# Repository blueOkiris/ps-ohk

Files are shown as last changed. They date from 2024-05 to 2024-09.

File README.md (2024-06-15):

# Polymath-Studio One-Handed Keyboard

## Description

Type with only one hand

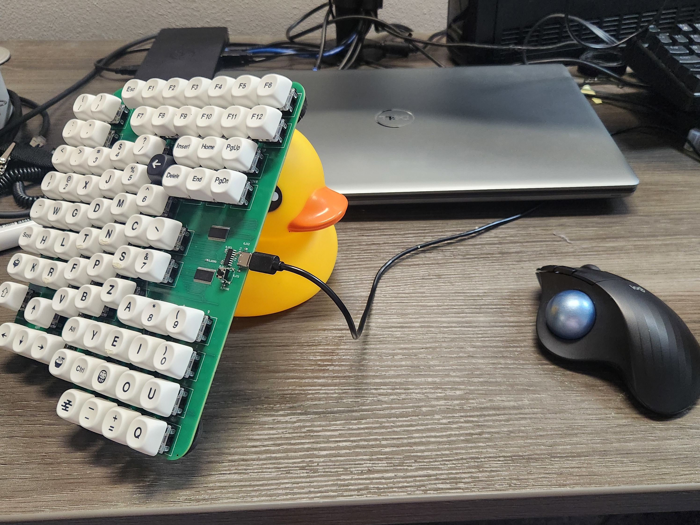
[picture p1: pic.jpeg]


Designed around

1) the most common letters used
2) relationships between sounds
3) the shape of a left hand
4) practicality

The PS-OHK (pronounced "psawk" [p͡sɑk̚]) aims to be the ultimate one-handed typing experience all without special modifiers (a standard key count) and a layout that is relatively easy to get used to.

## Build and Upload

Dependencies:

- arduino-cli
- make
- sdcc
- ch55xtool
- libusb

Build with `make -C fw`

Hold program button down, plug in, let go of program button, and run `make -C fw upload` within 3 seconds

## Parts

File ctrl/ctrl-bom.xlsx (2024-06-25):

Comment | Designator | Footprint | Part #
CH552G | IC_MCU1 | SOP-16 | C111292
10k Ohm | R_I2C2,R_I2C1,R_ADDR1,R_PROG1 | 0603
100nF | C2,C1 | 0603
5.1k Ohm | R_CC2,R_CC1 | 0603
PCA9505DGGY | IC_IOEXP2,IC_IOEXP1 | SOP50 P810X120-56N
USB-C Con | J_USB1 | USB-C 16P | C2894898

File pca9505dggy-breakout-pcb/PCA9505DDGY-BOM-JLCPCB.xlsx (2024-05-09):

Comment | Designator | Footprint | JLCPCB Part#(optional)
PCA9505DGG | IC1 | SOP-56P | C2669685

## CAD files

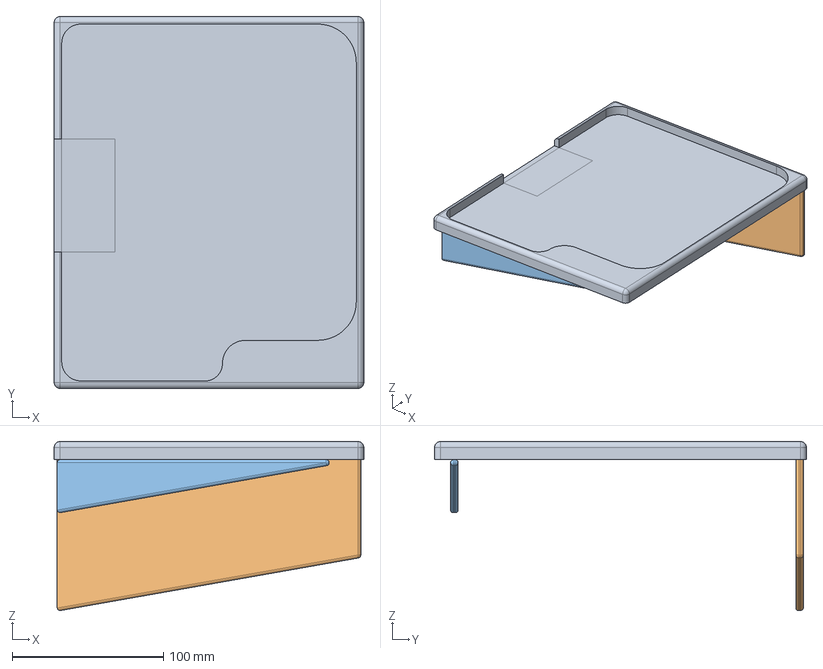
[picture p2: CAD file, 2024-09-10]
enclosure/ps-ohk-rh-enclosure.FCStd
204.5 x 245.6 x 111.6 mm
Keyboard Stand
Peg
Bottom Peg

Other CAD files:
enclosure/ps-ohk-rh-enclosure.stl

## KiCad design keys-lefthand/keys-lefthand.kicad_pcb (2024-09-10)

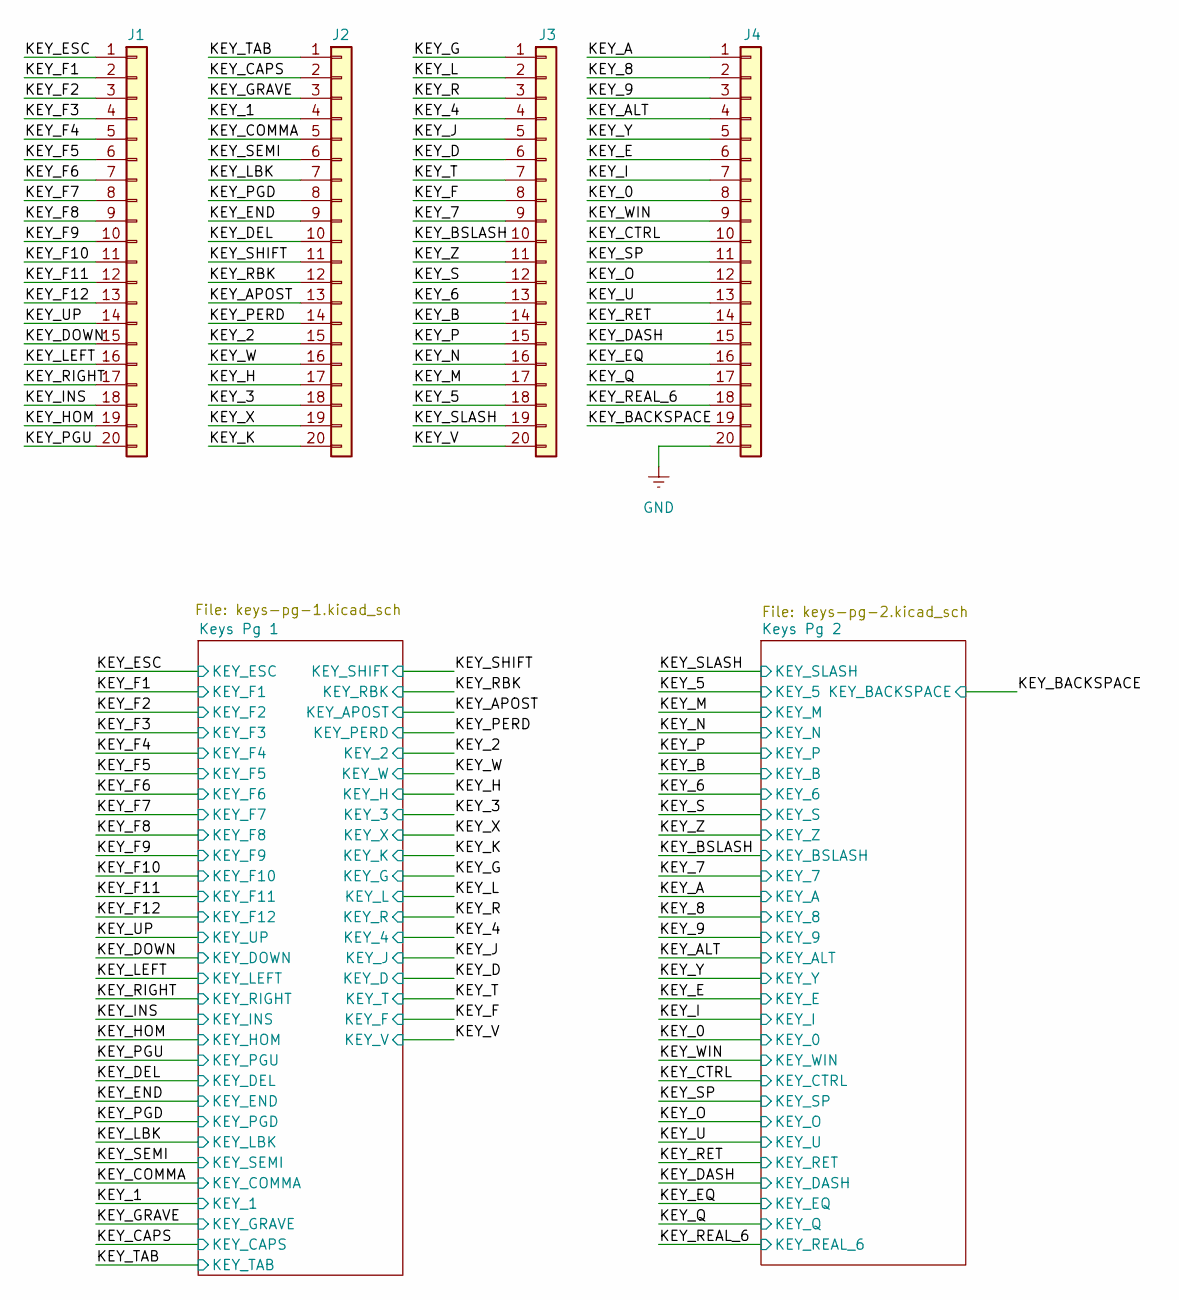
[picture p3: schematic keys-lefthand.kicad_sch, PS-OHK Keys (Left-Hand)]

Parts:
J1, J2, J3, J4: Conn_01x20; PinHeader_1x20_P2.54mm_Vertical

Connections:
/KEY_0: J4.8; also elsewhere on the board
/KEY_1: J2.4; also elsewhere on the board
/KEY_2: J2.15; also elsewhere on the board
/KEY_3: J2.18; also elsewhere on the board
/KEY_4: J3.4; also elsewhere on the board
/KEY_5: J3.18; also elsewhere on the board
/KEY_6: J3.13; also elsewhere on the board
/KEY_7: J3.9; also elsewhere on the board
/KEY_8: J4.2; also elsewhere on the board
/KEY_9: J4.3; also elsewhere on the board
/KEY_A: J4.1; also elsewhere on the board
/KEY_ALT: J4.4; also elsewhere on the board
/KEY_APOST: J2.13; also elsewhere on the board
/KEY_B: J3.14; also elsewhere on the board
/KEY_BACKSPACE: J4.19; also elsewhere on the board
/KEY_BSLASH: J3.10; also elsewhere on the board
/KEY_CAPS: J2.2; also elsewhere on the board
/KEY_COMMA: J2.5; also elsewhere on the board
/KEY_CTRL: J4.10; also elsewhere on the board
/KEY_D: J3.6; also elsewhere on the board
/KEY_DASH: J4.15; also elsewhere on the board
/KEY_DEL: J2.10; also elsewhere on the board
/KEY_DOWN: J1.15; also elsewhere on the board
/KEY_E: J4.6; also elsewhere on the board
/KEY_END: J2.9; also elsewhere on the board
/KEY_EQ: J4.16; also elsewhere on the board
/KEY_ESC: J1.1; also elsewhere on the board
/KEY_F: J3.8; also elsewhere on the board
/KEY_F1: J1.2; also elsewhere on the board
/KEY_F2: J1.3; also elsewhere on the board
/KEY_F3: J1.4; also elsewhere on the board
/KEY_F4: J1.5; also elsewhere on the board
/KEY_F5: J1.6; also elsewhere on the board
/KEY_F6: J1.7; also elsewhere on the board
/KEY_F7: J1.8; also elsewhere on the board
/KEY_F8: J1.9; also elsewhere on the board
/KEY_F9: J1.10; also elsewhere on the board
/KEY_F10: J1.11; also elsewhere on the board
/KEY_F11: J1.12; also elsewhere on the board
/KEY_F12: J1.13; also elsewhere on the board
/KEY_G: J3.1; also elsewhere on the board
/KEY_GRAVE: J2.3; also elsewhere on the board
/KEY_H: J2.17; also elsewhere on the board
/KEY_HOM: J1.19; also elsewhere on the board
/KEY_I: J4.7; also elsewhere on the board
/KEY_INS: J1.18; also elsewhere on the board
/KEY_J: J3.5; also elsewhere on the board
/KEY_K: J2.20; also elsewhere on the board
/KEY_L: J3.2; also elsewhere on the board
/KEY_LBK: J2.7; also elsewhere on the board
/KEY_LEFT: J1.16; also elsewhere on the board
/KEY_M: J3.17; also elsewhere on the board
/KEY_N: J3.16; also elsewhere on the board
/KEY_O: J4.12; also elsewhere on the board
/KEY_P: J3.15; also elsewhere on the board
/KEY_PERD: J2.14; also elsewhere on the board
/KEY_PGD: J2.8; also elsewhere on the board
/KEY_PGU: J1.20; also elsewhere on the board
/KEY_Q: J4.17; also elsewhere on the board
/KEY_R: J3.3; also elsewhere on the board
/KEY_RBK: J2.12; also elsewhere on the board
/KEY_REAL_6: J4.18; also elsewhere on the board
/KEY_RET: J4.14; also elsewhere on the board
/KEY_RIGHT: J1.17; also elsewhere on the board
/KEY_S: J3.12; also elsewhere on the board
/KEY_SEMI: J2.6; also elsewhere on the board
/KEY_SHIFT: J2.11; also elsewhere on the board
/KEY_SLASH: J3.19; also elsewhere on the board
/KEY_SP: J4.11; also elsewhere on the board
/KEY_T: J3.7; also elsewhere on the board
/KEY_TAB: J2.1; also elsewhere on the board
/KEY_U: J4.13; also elsewhere on the board
/KEY_UP: J1.14; also elsewhere on the board
/KEY_V: J3.20; also elsewhere on the board
/KEY_W: J2.16; also elsewhere on the board
/KEY_WIN: J4.9; also elsewhere on the board
/KEY_X: J2.19; also elsewhere on the board
/KEY_Y: J4.5; also elsewhere on the board
/KEY_Z: J3.11; also elsewhere on the board
GND: J4.20; also elsewhere on the board

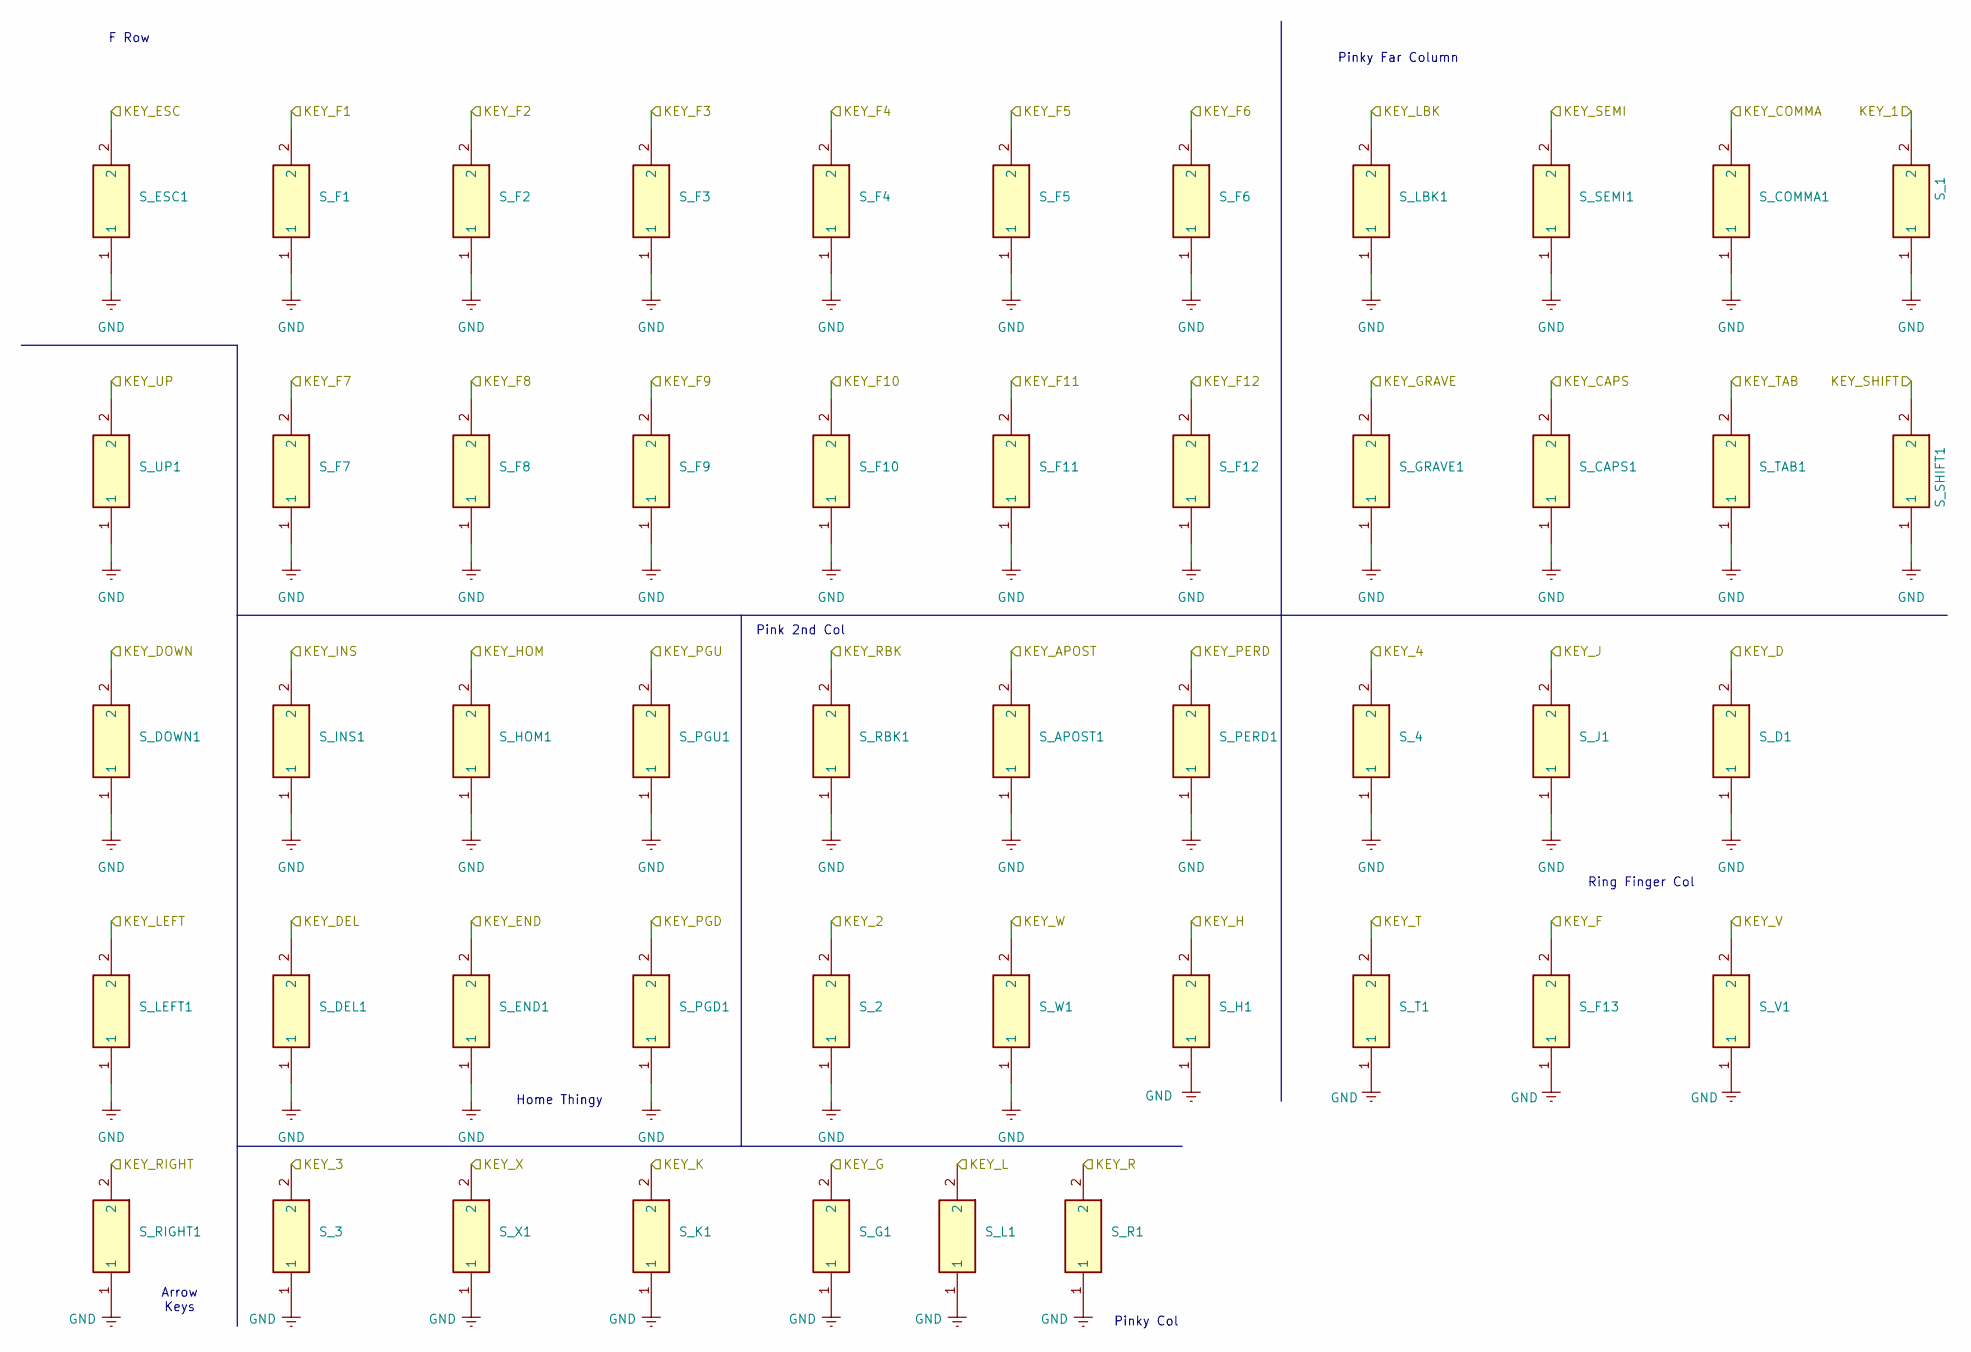
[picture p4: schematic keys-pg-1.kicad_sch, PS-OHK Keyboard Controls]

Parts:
S_1, S_2, S_3, S_4: COM13834; Mouser Part Number 474-COM-13834
S_APOST1: COM13834; Mouser Part Number 474-COM-13834
S_CAPS1: COM13834; Mouser Part Number 474-COM-13834
S_COMMA1: COM13834; Mouser Part Number 474-COM-13834
S_D1: COM13834; Mouser Part Number 474-COM-13834
S_DEL1: COM13834; Mouser Part Number 474-COM-13834
S_DOWN1: COM13834; Mouser Part Number 474-COM-13834
S_END1: COM13834; Mouser Part Number 474-COM-13834
S_ESC1: COM13834; Mouser Part Number 474-COM-13834
S_F1, S_F2, S_F3, S_F4, S_F5, S_F6, S_F7, S_F8, S_F9, S_F10, S_F11, S_F12, S_F13: COM13834; Mouser Part Number 474-COM-13834
S_G1: COM13834; Mouser Part Number 474-COM-13834
S_GRAVE1: COM13834; Mouser Part Number 474-COM-13834
S_H1: COM13834; Mouser Part Number 474-COM-13834
S_HOM1: COM13834; Mouser Part Number 474-COM-13834
S_INS1: COM13834; Mouser Part Number 474-COM-13834
S_J1: COM13834; Mouser Part Number 474-COM-13834
S_K1: COM13834; Mouser Part Number 474-COM-13834
S_L1: COM13834; Mouser Part Number 474-COM-13834
S_LBK1: COM13834; Mouser Part Number 474-COM-13834
S_LEFT1: COM13834; Mouser Part Number 474-COM-13834
S_PERD1: COM13834; Mouser Part Number 474-COM-13834
S_PGD1: COM13834; Mouser Part Number 474-COM-13834
S_PGU1: COM13834; Mouser Part Number 474-COM-13834
S_R1: COM13834; Mouser Part Number 474-COM-13834
S_RBK1: COM13834; Mouser Part Number 474-COM-13834
S_RIGHT1: COM13834; Mouser Part Number 474-COM-13834
S_SEMI1: COM13834; Mouser Part Number 474-COM-13834
S_SHIFT1: COM13834; Mouser Part Number 474-COM-13834
S_T1: COM13834; Mouser Part Number 474-COM-13834
S_TAB1: COM13834; Mouser Part Number 474-COM-13834
S_UP1: COM13834; Mouser Part Number 474-COM-13834
S_V1: COM13834; Mouser Part Number 474-COM-13834
S_W1: COM13834; Mouser Part Number 474-COM-13834
S_X1: COM13834; Mouser Part Number 474-COM-13834

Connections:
/KEY_1: S_1.2; also elsewhere on the board
/KEY_2: S_2.2; also elsewhere on the board
/KEY_3: S_3.2; also elsewhere on the board
/KEY_4: S_4.2; also elsewhere on the board
/KEY_APOST: S_APOST1.2; also elsewhere on the board
/KEY_CAPS: S_CAPS1.2; also elsewhere on the board
/KEY_COMMA: S_COMMA1.2; also elsewhere on the board
/KEY_D: S_D1.2; also elsewhere on the board
/KEY_DEL: S_DEL1.2; also elsewhere on the board
/KEY_DOWN: S_DOWN1.2; also elsewhere on the board
/KEY_END: S_END1.2; also elsewhere on the board
/KEY_ESC: S_ESC1.2; also elsewhere on the board
/KEY_F: S_F13.2; also elsewhere on the board
/KEY_F1: S_F1.2; also elsewhere on the board
/KEY_F2: S_F2.2; also elsewhere on the board
/KEY_F3: S_F3.2; also elsewhere on the board
/KEY_F4: S_F4.2; also elsewhere on the board
/KEY_F5: S_F5.2; also elsewhere on the board
/KEY_F6: S_F6.2; also elsewhere on the board
/KEY_F7: S_F7.2; also elsewhere on the board
/KEY_F8: S_F8.2; also elsewhere on the board
/KEY_F9: S_F9.2; also elsewhere on the board
/KEY_F10: S_F10.2; also elsewhere on the board
/KEY_F11: S_F11.2; also elsewhere on the board
/KEY_F12: S_F12.2; also elsewhere on the board
/KEY_G: S_G1.2; also elsewhere on the board
/KEY_GRAVE: S_GRAVE1.2; also elsewhere on the board
/KEY_H: S_H1.2; also elsewhere on the board
/KEY_HOM: S_HOM1.2; also elsewhere on the board
/KEY_INS: S_INS1.2; also elsewhere on the board
/KEY_J: S_J1.2; also elsewhere on the board
/KEY_K: S_K1.2; also elsewhere on the board
/KEY_L: S_L1.2; also elsewhere on the board
/KEY_LBK: S_LBK1.2; also elsewhere on the board
/KEY_LEFT: S_LEFT1.2; also elsewhere on the board
/KEY_PERD: S_PERD1.2; also elsewhere on the board
/KEY_PGD: S_PGD1.2; also elsewhere on the board
/KEY_PGU: S_PGU1.2; also elsewhere on the board
/KEY_R: S_R1.2; also elsewhere on the board
/KEY_RBK: S_RBK1.2; also elsewhere on the board
/KEY_RIGHT: S_RIGHT1.2; also elsewhere on the board
/KEY_SEMI: S_SEMI1.2; also elsewhere on the board
/KEY_SHIFT: S_SHIFT1.2; also elsewhere on the board
/KEY_T: S_T1.2; also elsewhere on the board
/KEY_TAB: S_TAB1.2; also elsewhere on the board
/KEY_UP: S_UP1.2; also elsewhere on the board
/KEY_V: S_V1.2; also elsewhere on the board
/KEY_W: S_W1.2; also elsewhere on the board
/KEY_X: S_X1.2; also elsewhere on the board
GND: S_1.1, S_2.1, S_3.1, S_4.1, S_APOST1.1, S_CAPS1.1, S_COMMA1.1, S_D1.1, S_DEL1.1, S_DOWN1.1, S_END1.1, S_ESC1.1, S_F1.1, S_F2.1, S_F3.1, S_F4.1, S_F5.1, S_F6.1, S_F7.1, S_F8.1, S_F9.1, S_F10.1, S_F11.1, S_F12.1, S_F13.1, S_G1.1, S_GRAVE1.1, S_H1.1, S_HOM1.1, S_INS1.1, S_J1.1, S_K1.1, S_L1.1, S_LBK1.1, S_LEFT1.1, S_PERD1.1, S_PGD1.1, S_PGU1.1, S_R1.1, S_RBK1.1, S_RIGHT1.1, S_SEMI1.1, S_SHIFT1.1, S_T1.1, S_TAB1.1, S_UP1.1, S_V1.1, S_W1.1, S_X1.1; also elsewhere on the board

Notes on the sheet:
Pink 2nd Col
Pinky Far Column
Pinky Col
Ring Finger Col
Arrow Keys
Home Thingy
F Row

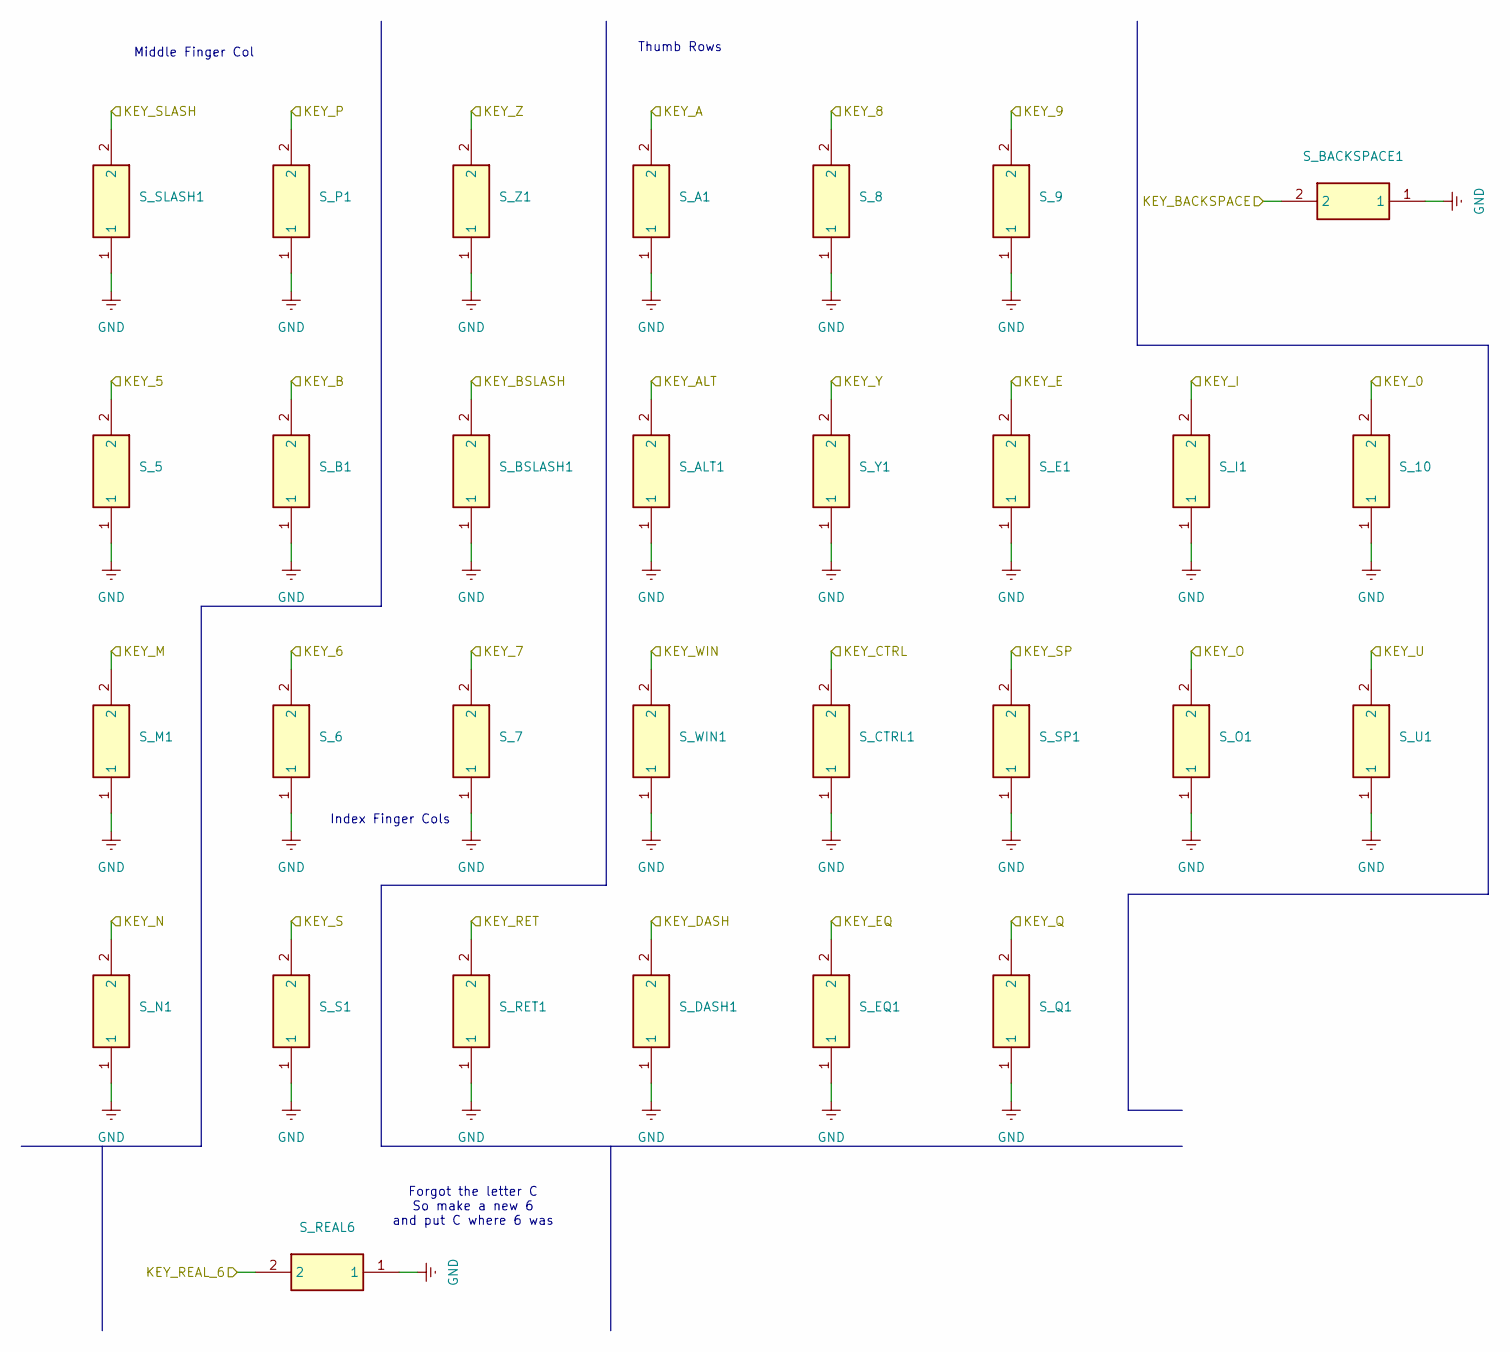
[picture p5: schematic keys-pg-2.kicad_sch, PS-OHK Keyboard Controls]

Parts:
S_5, S_6, S_7, S_8, S_9, S_10: COM13834; Mouser Part Number 474-COM-13834
S_A1: COM13834; Mouser Part Number 474-COM-13834
S_ALT1: COM13834; Mouser Part Number 474-COM-13834
S_B1: COM13834; Mouser Part Number 474-COM-13834
S_BACKSPACE1: COM13834; Mouser Part Number 474-COM-13834
S_BSLASH1: COM13834; Mouser Part Number 474-COM-13834
S_CTRL1: COM13834; Mouser Part Number 474-COM-13834
S_DASH1: COM13834; Mouser Part Number 474-COM-13834
S_E1: COM13834; Mouser Part Number 474-COM-13834
S_EQ1: COM13834; Mouser Part Number 474-COM-13834
S_I1: COM13834; Mouser Part Number 474-COM-13834
S_M1: COM13834; Mouser Part Number 474-COM-13834
S_N1: COM13834; Mouser Part Number 474-COM-13834
S_O1: COM13834; Mouser Part Number 474-COM-13834
S_P1: COM13834; Mouser Part Number 474-COM-13834
S_Q1: COM13834; Mouser Part Number 474-COM-13834
S_REAL6: COM13834; Mouser Part Number 474-COM-13834
S_RET1: COM13834; Mouser Part Number 474-COM-13834
S_S1: COM13834; Mouser Part Number 474-COM-13834
S_SLASH1: COM13834; Mouser Part Number 474-COM-13834
S_SP1: COM13834; Mouser Part Number 474-COM-13834
S_U1: COM13834; Mouser Part Number 474-COM-13834
S_WIN1: COM13834; Mouser Part Number 474-COM-13834
S_Y1: COM13834; Mouser Part Number 474-COM-13834
S_Z1: COM13834; Mouser Part Number 474-COM-13834

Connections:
/KEY_0: S_10.2; also elsewhere on the board
/KEY_5: S_5.2; also elsewhere on the board
/KEY_6: S_6.2; also elsewhere on the board
/KEY_7: S_7.2; also elsewhere on the board
/KEY_8: S_8.2; also elsewhere on the board
/KEY_9: S_9.2; also elsewhere on the board
/KEY_A: S_A1.2; also elsewhere on the board
/KEY_ALT: S_ALT1.2; also elsewhere on the board
/KEY_B: S_B1.2; also elsewhere on the board
/KEY_BACKSPACE: S_BACKSPACE1.2; also elsewhere on the board
/KEY_BSLASH: S_BSLASH1.2; also elsewhere on the board
/KEY_CTRL: S_CTRL1.2; also elsewhere on the board
/KEY_DASH: S_DASH1.2; also elsewhere on the board
/KEY_E: S_E1.2; also elsewhere on the board
/KEY_EQ: S_EQ1.2; also elsewhere on the board
/KEY_I: S_I1.2; also elsewhere on the board
/KEY_M: S_M1.2; also elsewhere on the board
/KEY_N: S_N1.2; also elsewhere on the board
/KEY_O: S_O1.2; also elsewhere on the board
/KEY_P: S_P1.2; also elsewhere on the board
/KEY_Q: S_Q1.2; also elsewhere on the board
/KEY_REAL_6: S_REAL6.2; also elsewhere on the board
/KEY_RET: S_RET1.2; also elsewhere on the board
/KEY_S: S_S1.2; also elsewhere on the board
/KEY_SLASH: S_SLASH1.2; also elsewhere on the board
/KEY_SP: S_SP1.2; also elsewhere on the board
/KEY_U: S_U1.2; also elsewhere on the board
/KEY_WIN: S_WIN1.2; also elsewhere on the board
/KEY_Y: S_Y1.2; also elsewhere on the board
/KEY_Z: S_Z1.2; also elsewhere on the board
GND: S_5.1, S_6.1, S_7.1, S_8.1, S_9.1, S_10.1, S_A1.1, S_ALT1.1, S_B1.1, S_BACKSPACE1.1, S_BSLASH1.1, S_CTRL1.1, S_DASH1.1, S_E1.1, S_EQ1.1, S_I1.1, S_M1.1, S_N1.1, S_O1.1, S_P1.1, S_Q1.1, S_REAL6.1, S_RET1.1, S_S1.1, S_SLASH1.1, S_SP1.1, S_U1.1, S_WIN1.1, S_Y1.1, S_Z1.1; also elsewhere on the board

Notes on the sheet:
Index Finger Cols
Forgot the letter C So make a new 6 and put C where 6 was
Thumb Rows
Middle Finger Col

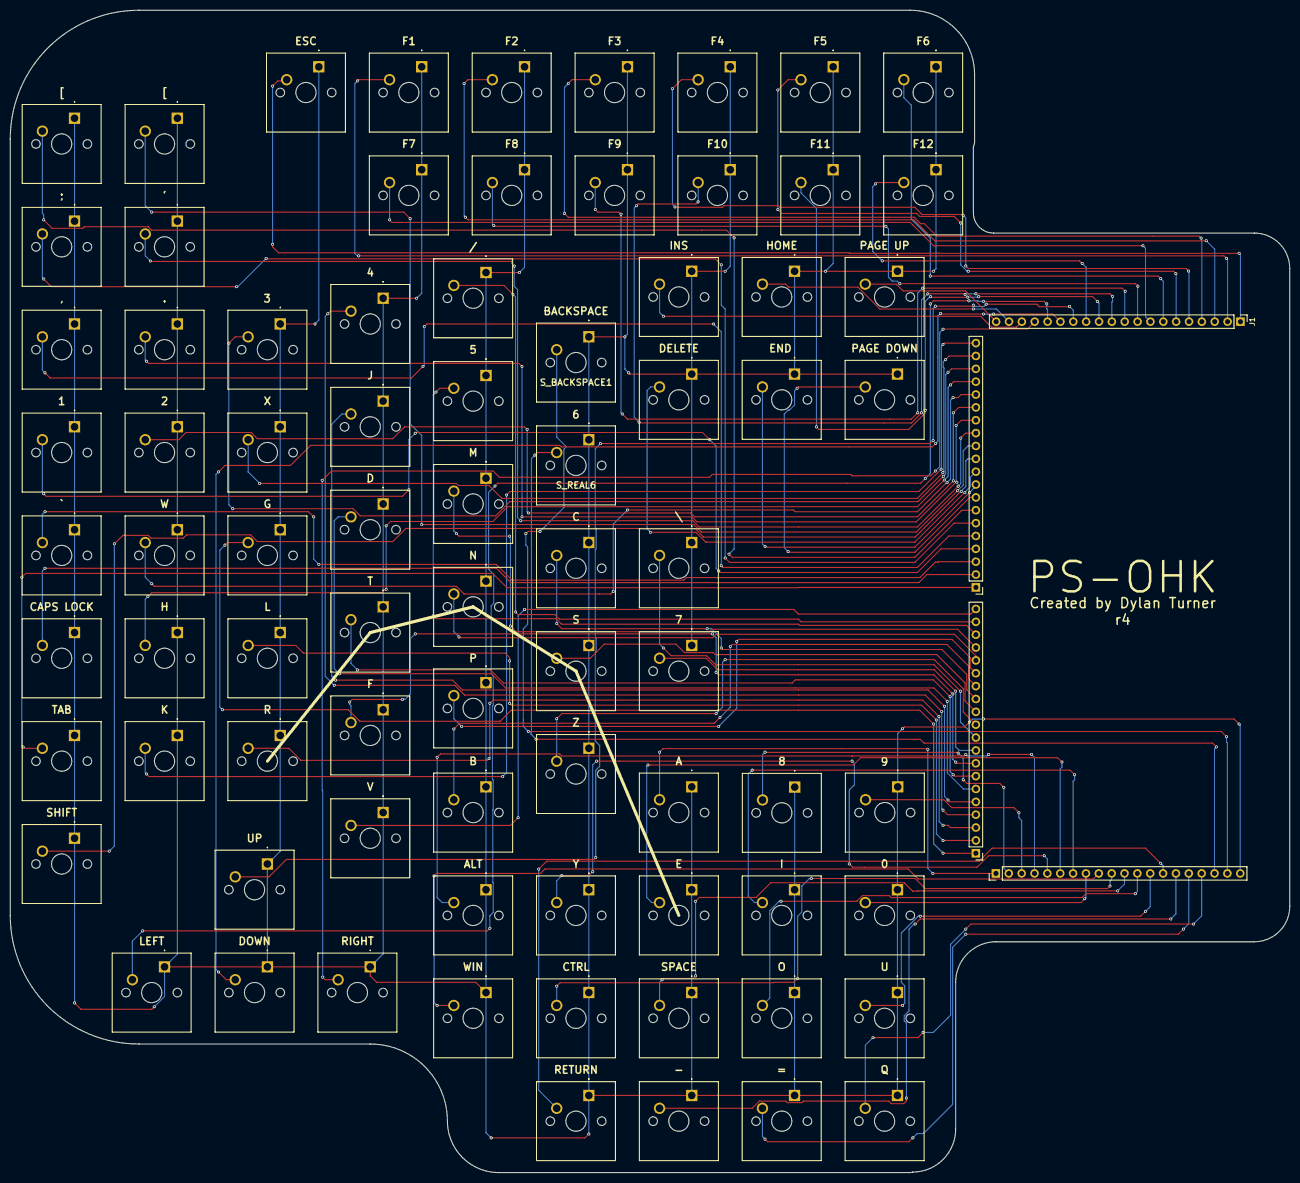
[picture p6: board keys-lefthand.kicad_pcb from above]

Board: 2 copper layers, 252.8 x 229.6 mm, 83 parts (0 on the bottom side), 80 nets.

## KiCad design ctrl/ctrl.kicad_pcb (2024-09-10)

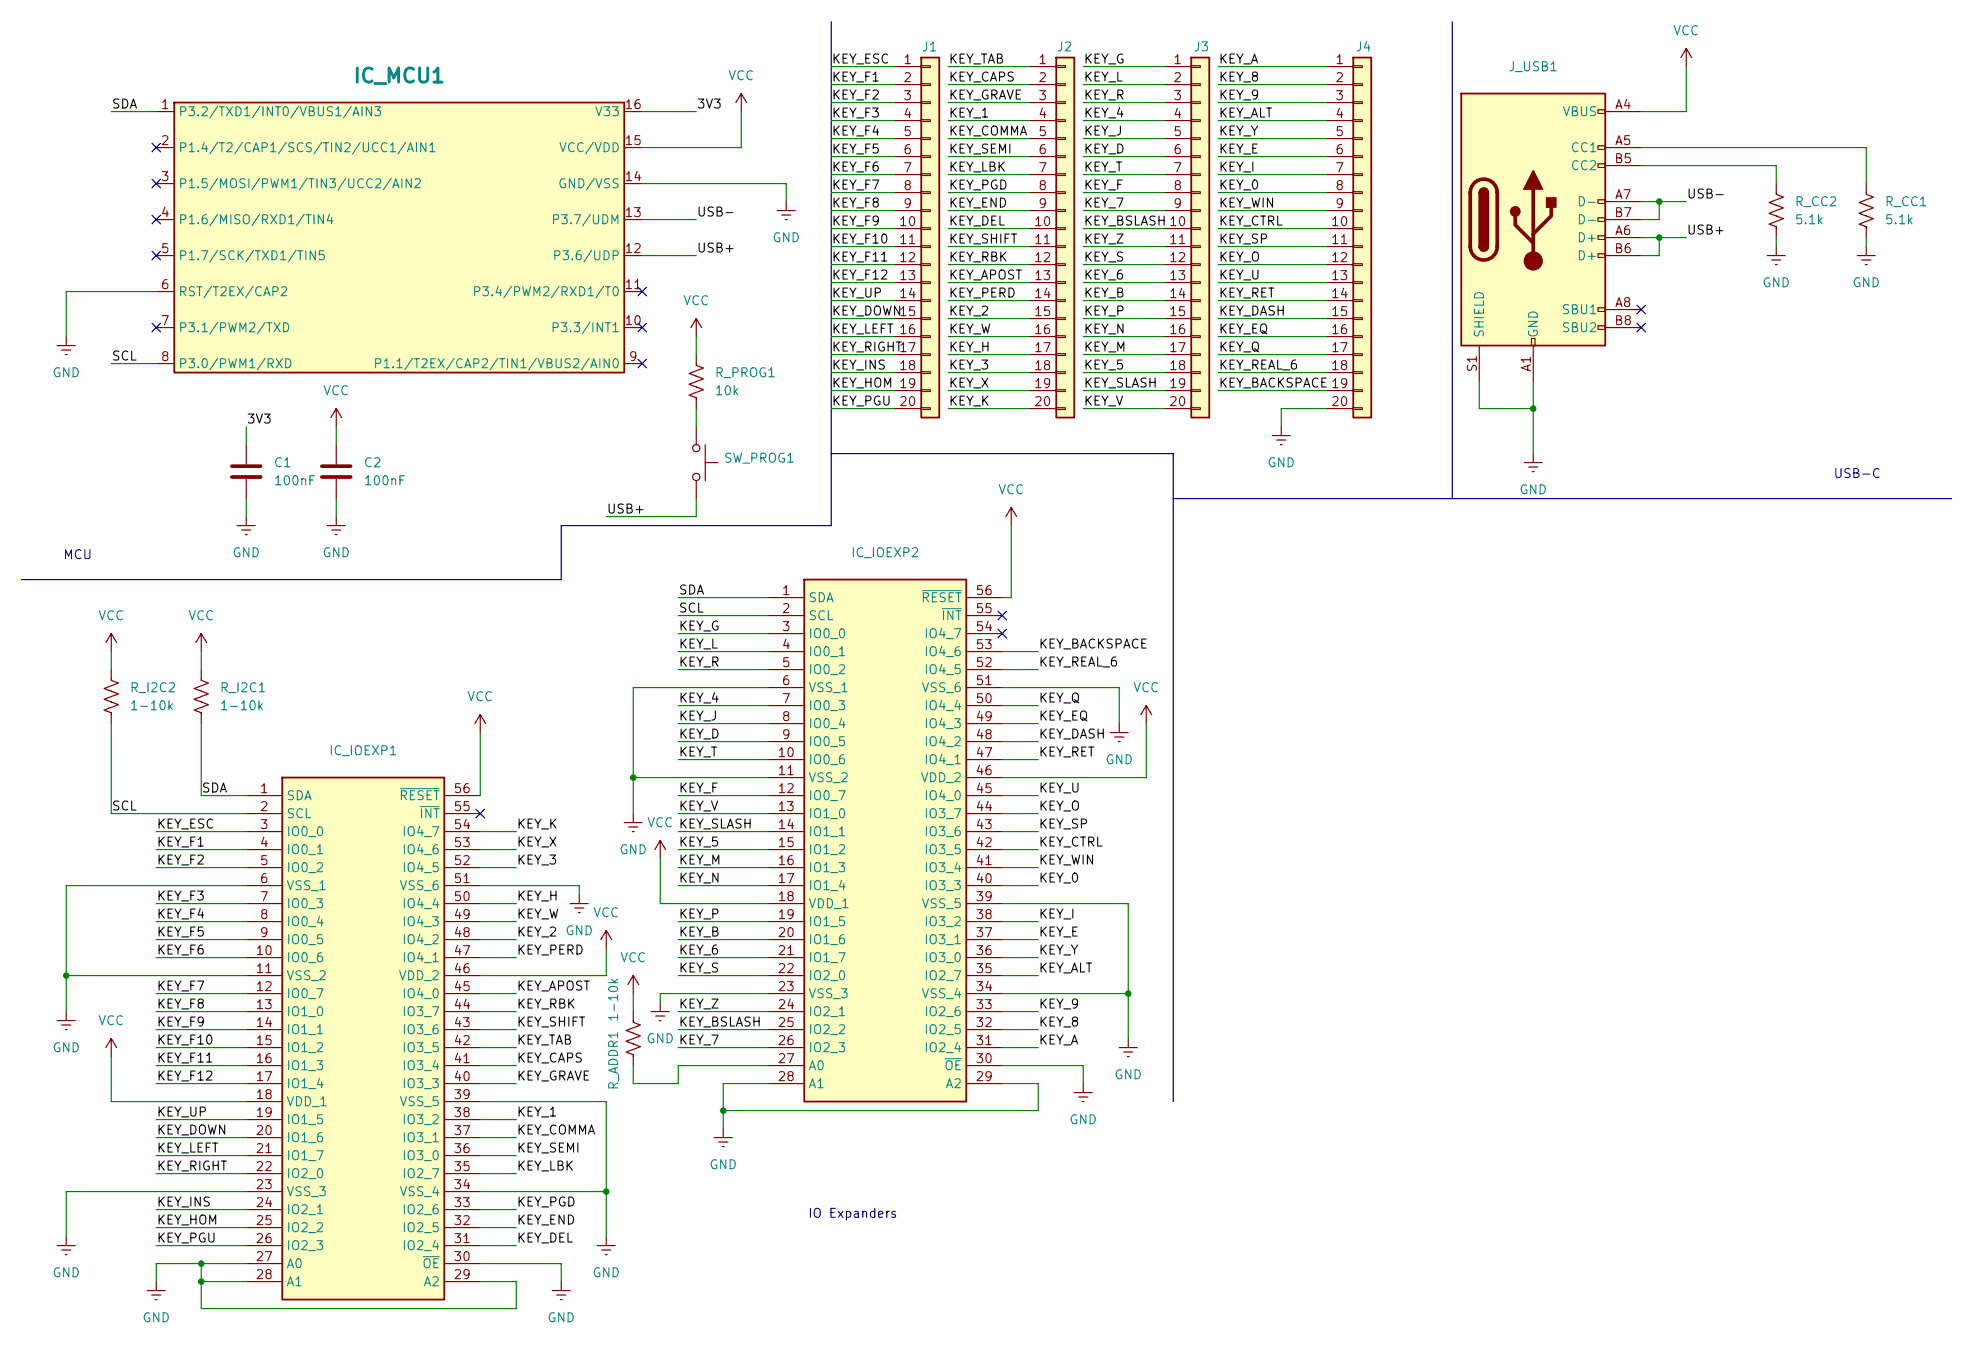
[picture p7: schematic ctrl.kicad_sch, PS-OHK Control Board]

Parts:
C1, C2: 100nF; C_0603_1608Metric
IC_IOEXP1, IC_IOEXP2: SOP50P810X120-56N; Mouser Part Number 771-PCA9505DGGY
IC_MCU1: SOIC-16_3.9x9.9mm_Pitch1.27mm
J1, J2, J3, J4: Conn_01x20; PinHeader_1x20_P2.54mm_Vertical
J_USB1: USB_C_Receptacle_HCTL_HC-TYPE-C-16P-01A
R_ADDR1: 1-10k; R_0603_1608Metric
R_CC1, R_CC2: 5.1k; R_0603_1608Metric
R_I2C1, R_I2C2: 1-10k; R_0603_1608Metric
R_PROG1: 10k; R_0603_1608Metric
SW_PROG1: SW_Push_1P1T_NO_6x6mm_H9.5mm

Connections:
/3V3: C1.1, IC_MCU1.16 (V33)
/KEY_0: IC_IOEXP2.40 (IO3_3), J4.8
/KEY_1: IC_IOEXP1.38 (IO3_2), J2.4
/KEY_2: IC_IOEXP1.48 (IO4_2), J2.15
/KEY_3: IC_IOEXP1.52 (IO4_5), J2.18
/KEY_4: IC_IOEXP2.7 (IO0_3), J3.4
/KEY_5: IC_IOEXP2.15 (IO1_2), J3.18
/KEY_6: IC_IOEXP2.21 (IO1_7), J3.13
/KEY_7: IC_IOEXP2.26 (IO2_3), J3.9
/KEY_8: IC_IOEXP2.32 (IO2_5), J4.2
/KEY_9: IC_IOEXP2.33 (IO2_6), J4.3
/KEY_A: IC_IOEXP2.31 (IO2_4), J4.1
/KEY_ALT: IC_IOEXP2.35 (IO2_7), J4.4
/KEY_APOST: IC_IOEXP1.45 (IO4_0), J2.13
/KEY_B: IC_IOEXP2.20 (IO1_6), J3.14
/KEY_BACKSPACE: IC_IOEXP2.53 (IO4_6), J4.19
/KEY_BSLASH: IC_IOEXP2.25 (IO2_2), J3.10
/KEY_CAPS: IC_IOEXP1.41 (IO3_4), J2.2
/KEY_COMMA: IC_IOEXP1.37 (IO3_1), J2.5
/KEY_CTRL: IC_IOEXP2.42 (IO3_5), J4.10
/KEY_D: IC_IOEXP2.9 (IO0_5), J3.6
/KEY_DASH: IC_IOEXP2.48 (IO4_2), J4.15
/KEY_DEL: IC_IOEXP1.31 (IO2_4), J2.10
/KEY_DOWN: IC_IOEXP1.20 (IO1_6), J1.15
/KEY_E: IC_IOEXP2.37 (IO3_1), J4.6
/KEY_END: IC_IOEXP1.32 (IO2_5), J2.9
/KEY_EQ: IC_IOEXP2.49 (IO4_3), J4.16
/KEY_ESC: IC_IOEXP1.3 (IO0_0), J1.1
/KEY_F: IC_IOEXP2.12 (IO0_7), J3.8
/KEY_F1: IC_IOEXP1.4 (IO0_1), J1.2
/KEY_F2: IC_IOEXP1.5 (IO0_2), J1.3
/KEY_F3: IC_IOEXP1.7 (IO0_3), J1.4
/KEY_F4: IC_IOEXP1.8 (IO0_4), J1.5
/KEY_F5: IC_IOEXP1.9 (IO0_5), J1.6
/KEY_F6: IC_IOEXP1.10 (IO0_6), J1.7
/KEY_F7: IC_IOEXP1.12 (IO0_7), J1.8
/KEY_F8: IC_IOEXP1.13 (IO1_0), J1.9
/KEY_F9: IC_IOEXP1.14 (IO1_1), J1.10
/KEY_F10: IC_IOEXP1.15 (IO1_2), J1.11
/KEY_F11: IC_IOEXP1.16 (IO1_3), J1.12
/KEY_F12: IC_IOEXP1.17 (IO1_4), J1.13
/KEY_G: IC_IOEXP2.3 (IO0_0), J3.1
/KEY_GRAVE: IC_IOEXP1.40 (IO3_3), J2.3
/KEY_H: IC_IOEXP1.50 (IO4_4), J2.17
/KEY_HOM: IC_IOEXP1.25 (IO2_2), J1.19
/KEY_I: IC_IOEXP2.38 (IO3_2), J4.7
/KEY_INS: IC_IOEXP1.24 (IO2_1), J1.18
/KEY_J: IC_IOEXP2.8 (IO0_4), J3.5
/KEY_K: IC_IOEXP1.54 (IO4_7), J2.20
/KEY_L: IC_IOEXP2.4 (IO0_1), J3.2
/KEY_LBK: IC_IOEXP1.35 (IO2_7), J2.7
/KEY_LEFT: IC_IOEXP1.21 (IO1_7), J1.16
/KEY_M: IC_IOEXP2.16 (IO1_3), J3.17
/KEY_N: IC_IOEXP2.17 (IO1_4), J3.16
/KEY_O: IC_IOEXP2.44 (IO3_7), J4.12
/KEY_P: IC_IOEXP2.19 (IO1_5), J3.15
/KEY_PERD: IC_IOEXP1.47 (IO4_1), J2.14
/KEY_PGD: IC_IOEXP1.33 (IO2_6), J2.8
/KEY_PGU: IC_IOEXP1.26 (IO2_3), J1.20
/KEY_Q: IC_IOEXP2.50 (IO4_4), J4.17
/KEY_R: IC_IOEXP2.5 (IO0_2), J3.3
/KEY_RBK: IC_IOEXP1.44 (IO3_7), J2.12
/KEY_REAL_6: IC_IOEXP2.52 (IO4_5), J4.18
/KEY_RET: IC_IOEXP2.47 (IO4_1), J4.14
/KEY_RIGHT: IC_IOEXP1.22 (IO2_0), J1.17
/KEY_S: IC_IOEXP2.22 (IO2_0), J3.12
/KEY_SEMI: IC_IOEXP1.36 (IO3_0), J2.6
/KEY_SHIFT: IC_IOEXP1.43 (IO3_6), J2.11
/KEY_SLASH: IC_IOEXP2.14 (IO1_1), J3.19
/KEY_SP: IC_IOEXP2.43 (IO3_6), J4.11
/KEY_T: IC_IOEXP2.10 (IO0_6), J3.7
/KEY_TAB: IC_IOEXP1.42 (IO3_5), J2.1
/KEY_U: IC_IOEXP2.45 (IO4_0), J4.13
/KEY_UP: IC_IOEXP1.19 (IO1_5), J1.14
/KEY_V: IC_IOEXP2.13 (IO1_0), J3.20
/KEY_W: IC_IOEXP1.49 (IO4_3), J2.16
/KEY_WIN: IC_IOEXP2.41 (IO3_4), J4.9
/KEY_X: IC_IOEXP1.53 (IO4_6), J2.19
/KEY_Y: IC_IOEXP2.36 (IO3_0), J4.5
/KEY_Z: IC_IOEXP2.24 (IO2_1), J3.11
/SCL: IC_IOEXP1.2 (SCL), IC_IOEXP2.2 (SCL), IC_MCU1.8 (P3.0/PWM1/RXD), R_I2C2.2
/SDA: IC_IOEXP1.1 (SDA), IC_IOEXP2.1 (SDA), IC_MCU1.1 (P3.2/TXD1/INT0/VBUS1/AIN3), R_I2C1.2
/USB+: IC_MCU1.12 (P3.6/UDP), J_USB1.A6 (D+), J_USB1.B6 (D+), SW_PROG1.2
/USB-: IC_MCU1.13 (P3.7/UDM), J_USB1.A7 (D-), J_USB1.B7 (D-)
GND: C1.2, C2.2, IC_IOEXP1.6 (VSS_1), IC_IOEXP1.11 (VSS_2), IC_IOEXP1.23 (VSS_3), IC_IOEXP1.27 (A0), IC_IOEXP1.28 (A1), IC_IOEXP1.29 (A2), IC_IOEXP1.30 (~OE), IC_IOEXP1.34 (VSS_4), IC_IOEXP1.39 (VSS_5), IC_IOEXP1.51 (VSS_6), IC_IOEXP2.6 (VSS_1), IC_IOEXP2.11 (VSS_2), IC_IOEXP2.23 (VSS_3), IC_IOEXP2.28 (A1), IC_IOEXP2.29 (A2), IC_IOEXP2.30 (~OE), IC_IOEXP2.34 (VSS_4), IC_IOEXP2.39 (VSS_5), IC_IOEXP2.51 (VSS_6), IC_MCU1.6 (RST/T2EX/CAP2), IC_MCU1.14 (GND/VSS), J4.20, J_USB1.A1 (GND), J_USB1.A12 (GND), J_USB1.B1 (GND), J_USB1.B12 (GND), J_USB1.S1 (SHIELD), R_CC1.2, R_CC2.2
unnamed: IC_IOEXP2.27 (A0), R_ADDR1.2
unnamed: J_USB1.A5 (CC1), R_CC1.1
unnamed: J_USB1.B5 (CC2), R_CC2.1
unnamed: R_PROG1.2, SW_PROG1.1
VCC: C2.1, IC_IOEXP1.18 (VDD_1), IC_IOEXP1.46 (VDD_2), IC_IOEXP1.56 (~RESET), IC_IOEXP2.18 (VDD_1), IC_IOEXP2.46 (VDD_2), IC_IOEXP2.56 (~RESET), IC_MCU1.15 (VCC/VDD), J_USB1.A4 (VBUS), J_USB1.A9 (VBUS), J_USB1.B4 (VBUS), J_USB1.B9 (VBUS), R_ADDR1.1, R_I2C1.1, R_I2C2.1, R_PROG1.1

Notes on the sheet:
IO Expanders
USB-C
MCU

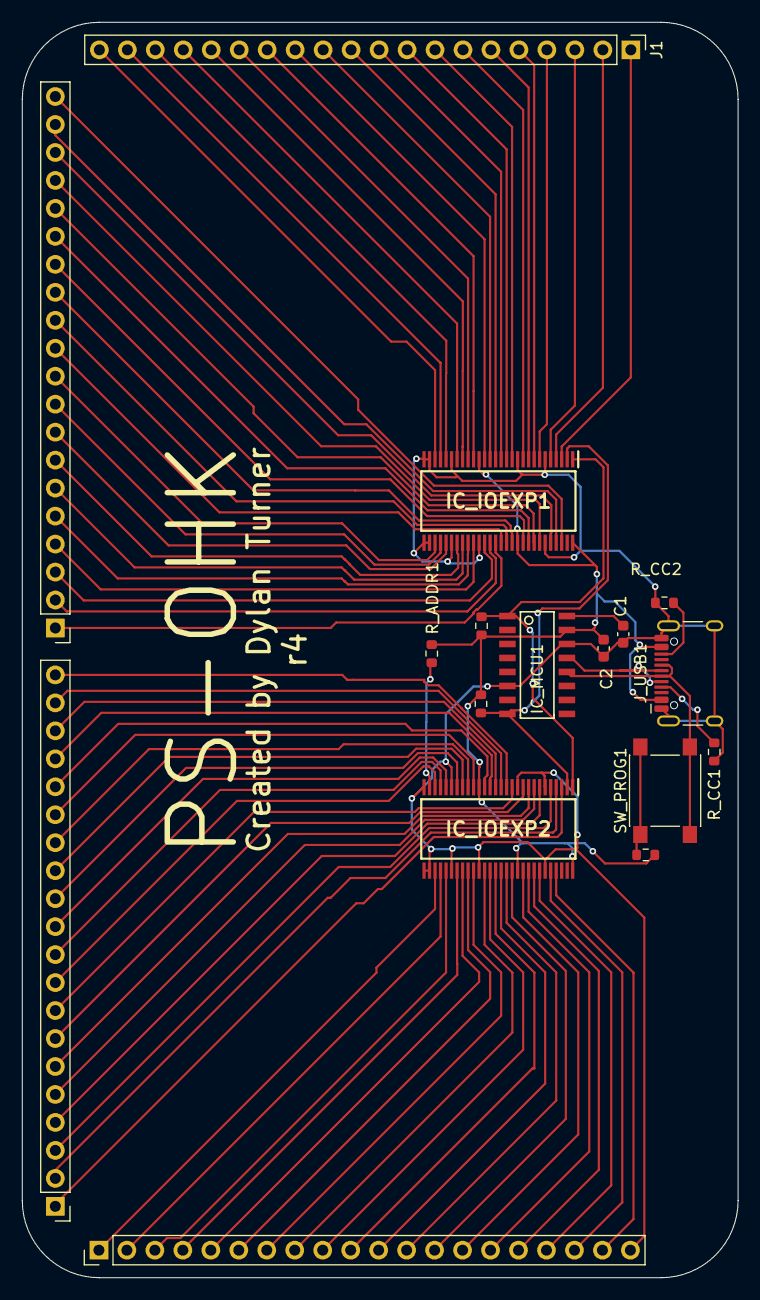
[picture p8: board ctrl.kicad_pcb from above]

Board: 2 copper layers, 65.0 x 114.0 mm, 17 parts (0 on the bottom side), 90 nets.

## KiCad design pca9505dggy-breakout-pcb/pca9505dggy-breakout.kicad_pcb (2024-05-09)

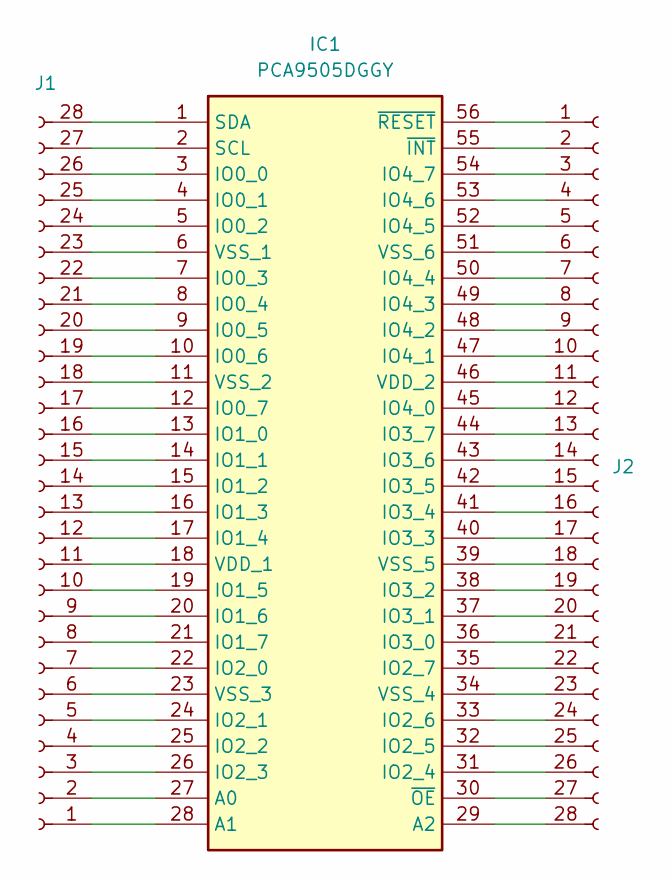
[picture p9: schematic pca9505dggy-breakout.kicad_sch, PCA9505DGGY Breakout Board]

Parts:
IC1: PCA9505DGGY; SOP50P810X120-56N; Mouser Part Number 771-PCA9505DGGY
J1, J2: PinHeader_1x28_P2.54mm_Vertical

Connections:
unnamed: IC1.27 (A0), J1.2
unnamed: IC1.28 (A1), J1.1
unnamed: IC1.29 (A2), J2.28
unnamed: IC1.3 (IO0_0), J1.26
unnamed: IC1.4 (IO0_1), J1.25
unnamed: IC1.5 (IO0_2), J1.24
unnamed: IC1.7 (IO0_3), J1.22
unnamed: IC1.8 (IO0_4), J1.21
unnamed: IC1.9 (IO0_5), J1.20
unnamed: IC1.10 (IO0_6), J1.19
unnamed: IC1.12 (IO0_7), J1.17
unnamed: IC1.13 (IO1_0), J1.16
unnamed: IC1.14 (IO1_1), J1.15
unnamed: IC1.15 (IO1_2), J1.14
unnamed: IC1.16 (IO1_3), J1.13
unnamed: IC1.17 (IO1_4), J1.12
unnamed: IC1.19 (IO1_5), J1.10
unnamed: IC1.20 (IO1_6), J1.9
unnamed: IC1.21 (IO1_7), J1.8
unnamed: IC1.22 (IO2_0), J1.7
unnamed: IC1.24 (IO2_1), J1.5
unnamed: IC1.25 (IO2_2), J1.4
unnamed: IC1.26 (IO2_3), J1.3
unnamed: IC1.31 (IO2_4), J2.26
unnamed: IC1.32 (IO2_5), J2.25
unnamed: IC1.33 (IO2_6), J2.24
unnamed: IC1.35 (IO2_7), J2.22
unnamed: IC1.36 (IO3_0), J2.21
unnamed: IC1.37 (IO3_1), J2.20
unnamed: IC1.38 (IO3_2), J2.19
unnamed: IC1.40 (IO3_3), J2.17
unnamed: IC1.41 (IO3_4), J2.16
unnamed: IC1.42 (IO3_5), J2.15
unnamed: IC1.43 (IO3_6), J2.14
unnamed: IC1.44 (IO3_7), J2.13
unnamed: IC1.45 (IO4_0), J2.12
unnamed: IC1.47 (IO4_1), J2.10
unnamed: IC1.48 (IO4_2), J2.9
unnamed: IC1.49 (IO4_3), J2.8
unnamed: IC1.50 (IO4_4), J2.7
unnamed: IC1.52 (IO4_5), J2.5
unnamed: IC1.53 (IO4_6), J2.4
unnamed: IC1.54 (IO4_7), J2.3
unnamed: IC1.2 (SCL), J1.27
unnamed: IC1.1 (SDA), J1.28
unnamed: IC1.18 (VDD_1), J1.11
unnamed: IC1.46 (VDD_2), J2.11
unnamed: IC1.6 (VSS_1), J1.23
unnamed: IC1.11 (VSS_2), J1.18
unnamed: IC1.23 (VSS_3), J1.6
unnamed: IC1.34 (VSS_4), J2.23
unnamed: IC1.39 (VSS_5), J2.18
unnamed: IC1.51 (VSS_6), J2.6
unnamed: IC1.55 (~INT), J2.2
unnamed: IC1.30 (~OE), J2.27
unnamed: IC1.56 (~RESET), J2.1

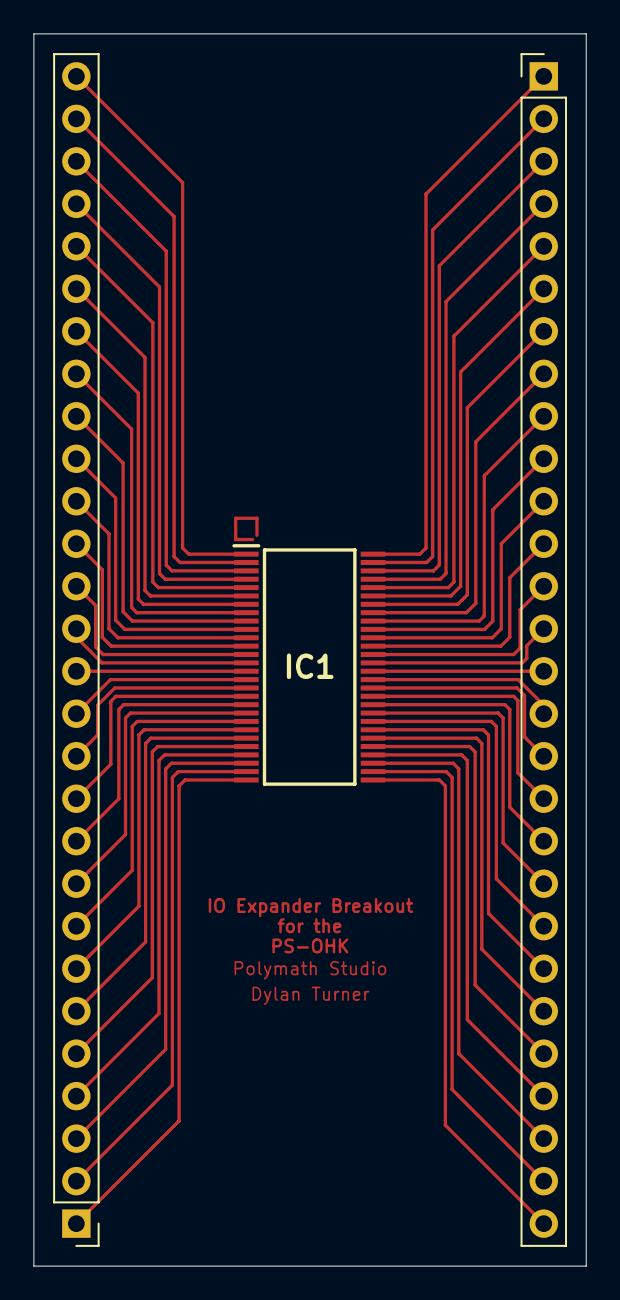
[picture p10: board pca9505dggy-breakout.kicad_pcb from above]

Board: 2 copper layers, 33.0 x 73.7 mm, 3 parts (0 on the bottom side), 56 nets.

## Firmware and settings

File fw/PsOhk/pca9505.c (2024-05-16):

// Implement PCA9505 functionality

#include <SoftI2C.h>
#include "pca9505.h"

#define NPORTS                  5

#define PCA9505_REG_MSK         0x20
#define PCA9505_REG_PI          0x10
#define PCA9505_REG_IOC         0x18
#define PCA9505_REG_IP          0x00

#define PCA9505_CMD_AI_ON       0x80
#define PCA9505_CMD_AI_OFF      0x00

typedef struct {
    uint8_t ports[NPORTS];
} io_ports_t;

static void set_io_interrupt(const uint8_t addr, const io_ports_t *const io);
static void set_io_polarity(const uint8_t addr, const io_ports_t *const io);
static void set_io_mode(const uint8_t addr, io_ports_t io);
static void send_io_data(const uint8_t addr, const uint8_t reg, const io_ports_t *const io);
static uint8_t recv_port_data(const uint8_t addr, const uint8_t reg, const uint8_t port);
static inline uint8_t get_port(const uint8_t pin);
static inline uint8_t get_bit(const uint8_t pin);

void gpio_init(const uint8_t addr, const uint8_t scl, const uint8_t sda) {
    scl_pin = scl;
    sda_pin = sda;
    I2CInit();

    const io_ports_t interrupt_cfg = { { 0xFF, 0xFF, 0xFF, 0xFF, 0xFF } };
    const io_ports_t pol_mode_cfg = { { 0 } };
    set_io_interrupt(addr, &interrupt_cfg);
    set_io_polarity(addr, &pol_mode_cfg);
    set_io_mode(addr, pol_mode_cfg);
}

uint8_t gpio_digital_read(const uint8_t addr, const uint8_t pin) {
    return recv_port_data(addr, PCA9505_REG_IP, get_port(pin)) & (1 << get_bit(pin)) ? 0 : 1;
}

static void set_io_interrupt(const uint8_t addr, const io_ports_t *const io) {
    send_io_data(addr, PCA9505_REG_MSK, io);
}

static void set_io_polarity(const uint8_t addr, const io_ports_t *const io) {
    send_io_data(addr, PCA9505_REG_PI, io);
}

static void set_io_mode(const uint8_t addr, io_ports_t io) {
    for (int i = 0; i < NPORTS; i++) {
        io.ports[i] = ~io.ports[i];
    }
    send_io_data(addr, PCA9505_REG_IOC, &io);
}

static void send_io_data(const uint8_t addr, const uint8_t reg, const io_ports_t *const io) {
    I2CStart();
    I2CSend(addr << 1);
    I2CSend(reg | PCA9505_CMD_AI_ON);
    for (int i = 0; i < NPORTS; i++) {
        I2CSend(io->ports[i]);
    }
    I2CStop();
}

static uint8_t recv_port_data(const uint8_t addr, const uint8_t reg, const uint8_t port) {
    I2CStart();
    I2CSend(addr << 1);
    I2CSend((reg + (port % 5)) | PCA9505_CMD_AI_OFF);
    I2CRestart();
    I2CSend(addr << 1 | 0x01);
    const uint8_t data = I2CRead();
    I2CStop();
    return data;
}

static uint8_t inline get_port(const uint8_t pin) {
    return pin / 8;
}

static inline uint8_t get_bit(const uint8_t pin) {
    return pin % 8;
}

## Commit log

2024-05-06 Initial commit: pcb w/ switches and layout derived
    [ps-ohk.kicad_pcb, ps-ohk.kicad_sch]
2024-05-06 Added 40-pin IO Expander to project
    Will make use of two of them
    [ps-ohk.kicad_pcb, ps-ohk.kicad_sch]
2024-05-09 pca9505ddgy-breakout: dev board for GPIO expander
    [PCA9505DDGY-BOM-JLCPCB.xlsx, pca9505dggy-breakout.kicad_pcb, pca9505dggy-breakout.kicad_sch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]
2024-05-16 fw: got HID working via CH55xDuino
    [PCA9505DDGY-BOM-JLCPCB.xlsx, pca9505dggy-breakout.kicad_pcb, pca9505dggy-breakout.kicad_sch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]
2024-05-16 fw: working pca9505 driver
2024-05-16 pcb: implement IO Expander circuit based on proto
    [ps-ohk.kicad_pcb, ps-ohk.kicad_sch]
2024-05-16 pcb: moved libraries into pcb folder for org.
    [ps-ohk.kicad_pcb]
2024-05-16 pca9505dggy-breakout-pcb: correct lib paths
2024-05-21 pcb: add buttons and route
    [keys-pg-1.kicad_sch, keys-pg-2.kicad_sch, ps-ohk.kicad_pcb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]
2024-06-01 pcb: made orderable on pcb-way
    [keys-pg-1.kicad_sch, keys-pg-2.kicad_sch, ps-ohk-bom.xlsx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]
2024-06-15 pcb: added C and rmd unneeded hardware
    [keys-pg-1.kicad_sch, keys-pg-2.kicad_sch, ps-ohk-bom.xlsx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]
2024-06-18 pcb: add backspace and move k
    [keys-pg-1.kicad_sch, keys-pg-2.kicad_sch, ps-ohk.kicad_pcb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]
2024-06-24 pcb: split into a control board and a keys board
    Reasoning:
    1. Should be cheaper to order an assembled control board + unassembled
    main board
    2. More flexible (can create a right-handed board as well)
    [ctrl.kicad_pcb, ctrl.kicad_sch, keys-lefthand.kicad_pcb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]
2024-06-25 Duplicated left-hand to make a right-handed vers
    [keys-pg-1.kicad_sch, keys-pg-2.kicad_sch, keys-righthand.kicad_pcb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]
2024-06-25 keys-righthand: wired up
    [keys-righthand.kicad_pcb]
2024-06-25 Ctrl+Keys: Fixed BOM/rmvd unused
    [ctrl-bom.xlsx, ps-ohk-bom.xlsx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]
2024-06-25 pcb: Update revision numbers
    [ctrl.kicad_pcb, ctrl.kicad_sch, keys-lefthand.kicad_pcb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]
2024-07-01 enclosure: initial version of right handed case
    [keys-righthand.kicad_pcb, ps-ohk-rh-enclosure-peg.3mf, ps-ohk-rh-enclosure-peg.stl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]
2024-07-01 Rm accidentally added outputs
    [ctrl-bottom-pos.csv, ctrl-top-pos.csv]
2024-07-09 enclosure: modify to correct fit and add slot
    [ps-ohk-rh-enclosure.3mf, ps-ohk-rh-enclosure.FCStd, ps-ohk-rh-enclosure.stl]
2024-09-10 r4: 1mm->2.54mm pins, no right-hand yet
    [ctrl.kicad_pcb, ctrl.kicad_sch, keys-lefthand.kicad_pcb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]
2024-09-10 enlosure: enclosure for right-handed
    [ps-ohk-rh-enclosure-peg-small.stl, ps-ohk-rh-enclosure-peg.3mf, ps-ohk-rh-enclosure.3mf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]
